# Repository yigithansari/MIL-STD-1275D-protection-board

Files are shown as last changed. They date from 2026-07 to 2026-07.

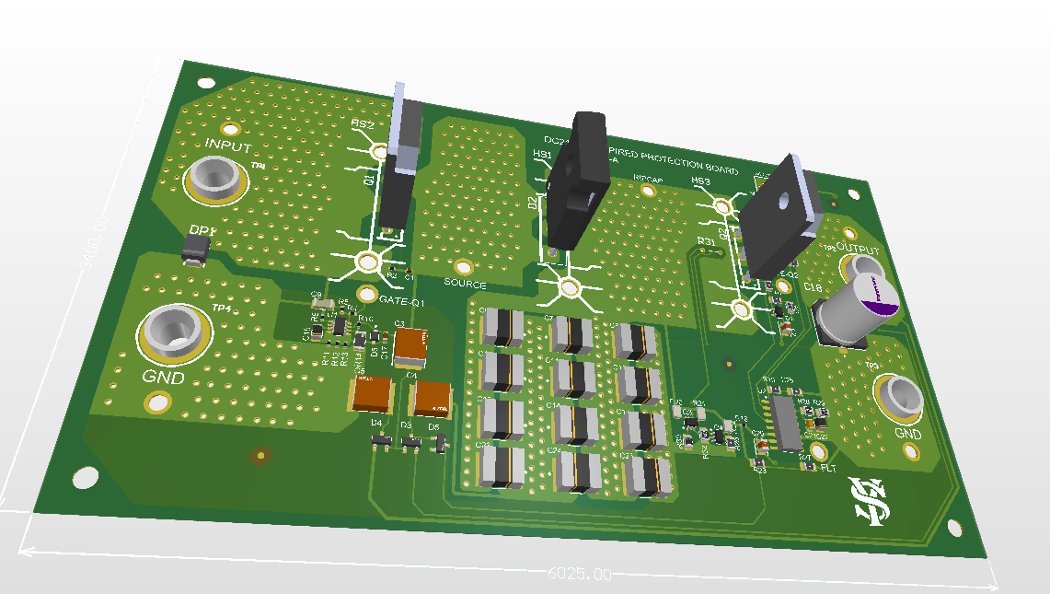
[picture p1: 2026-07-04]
images/pcb-renders/MIL_STD_1275D.png

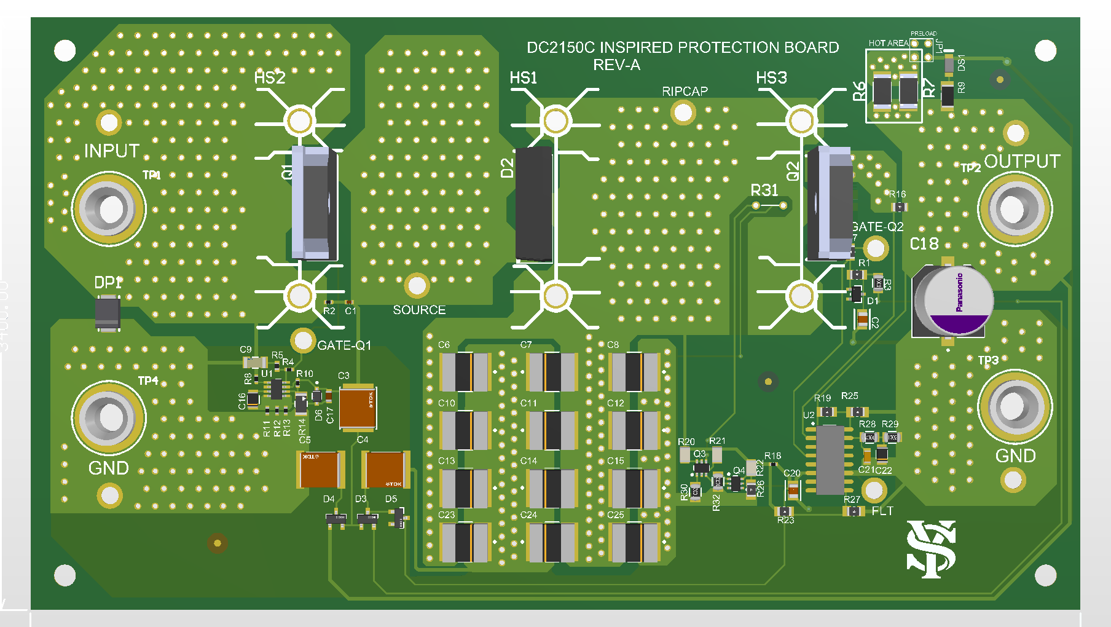
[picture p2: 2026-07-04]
images/pcb-renders/MIL_STD_1275D-TOP.png

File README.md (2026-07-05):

\# MIL-STD-1275D Inspired Protection Board

This repository documents a two-layer PCB design project for a 24 V military vehicle input protection board inspired by the Analog Devices DC2150C reference design.

The goal of this project was to study the DC2150C protection architecture, extract the recommended functional blocks and BOM structure, and recreate the schematic and PCB layout in Altium Designer as a hardware design portfolio project.

The board is focused on harsh DC input environments, especially MIL-STD-1275D-like 24 V / 28 V vehicle power bus conditions. It is not presented as a certified or fully validated MIL-STD-1275D-compliant product.

\## Project Status

Design completed.

This board has not yet been manufactured or electrically tested. The repository is shared as a design-only PCB portfolio project.

\## Design Objective

The objective of this design was to create a protection board for a nominal 24 V military vehicle input line using a DC2150C-inspired architecture.

The design focuses on:

\- Input transient protection

\- Surge stopper architecture

\- High-energy power path layout

\- Anti-ripple capacitor bank

\- Protected output generation

\- Current sensing

\- Reverse input blocking path based on the reference design structure

\- Two-layer manufacturable PCB layout

\## Reference Design Background

This project was inspired by the DC2150C reference design.

The original DC2150C architecture was studied to understand the functional role of each protection block. Based on that study, the schematic and PCB layout were recreated in Altium Designer as an independent design exercise.

This project should be understood as a learning and portfolio-oriented PCB implementation, not as a direct commercial product.

\## Main Functional Blocks

The schematic is divided into the following functional sections:

\- Power Guardian

\- LTC4366 front-end protection stage

\- Anti-ripple capacitor bank

\- Charge pump

\- LT4363 surge stopper stage

\- Input/output connection and indicator section

\## Key Components

Main components used in the design include:

\- `LTC4366`: High-voltage surge stopper controller used in the front-end protection section

\- `LT4363HS-2#PBF`: Surge stopper controller used for the protected output stage

\- External N-channel MOSFETs for the controlled power path

\- Bidirectional TVS diode at the input

\- Power diode path for reverse input blocking based on the DC2150C-inspired architecture

\- Current sense resistor for the LT4363 current limit path

\- Anti-ripple capacitor bank

\- Output capacitor for protected output stabilization

\- Status LED and output connection components

\## Protection Strategy

The protection architecture is based on a staged approach.

The input first passes through a front-end protection stage based around the LTC4366. This section controls the first MOSFET power path and helps protect the downstream circuit from high-voltage input transients.

The anti-ripple section uses a capacitor bank to support the intermediate supply node during ripple and transient conditions.

The LT4363-based surge stopper section controls the protected output path, monitors current through a sense element, and provides additional protection behavior at the output side.

A bidirectional TVS diode is included at the input as an additional transient suppression element. A power diode path is used as part of the reverse input protection approach inspired by the DC2150C reference design.

\## PCB Design

The board was designed as a two-layer PCB.

A two-layer stack-up was selected because the design is primarily a power-path protection board rather than a dense mixed-signal circuit. The layout uses wide copper areas for high-current paths and thermal spreading, while keeping the design simple to inspect and manufacture.

Main layout considerations:

\- Wide copper pours for input, source, RIPCAP, and output nodes

\- Large power pads for input and output terminals

\- Thermal via arrays under high-current and heat-generating copper areas

\- Separate placement of control ICs from main power copper regions

\- Short routing around MOSFET gate-drive and sense paths

\- Clearly labeled test points and power nodes

\- Board-level silkscreen labels for major functional nodes

\## Repository Structure

```text

mil-std-1275-protection-board/

├── README.md

├── hardware/

│   ├── altium-project/

│   ├── schematic-pdf/

│   ├── pcb-pdf/

│   ├── fabrication-outputs/

│   │   ├── gerber/

│   │   ├── nc-drill/

│   │   └── pick-and-place/

│   ├── bom/

│   

├── docs/

│   ├── design-notes.md

│   ├── protection-strategy.md

│   ├── layout-notes.md

│   └── reference-design-study.md

└── images/

\\\&#x20;   ├── pcb-renders/

\\\&#x20;   ├── schematic/

\\\&#x20;   └── layout/

\\\\## Hardware Files

The hardware package includes:

\\\\- Altium Designer project files

\\\\- Schematic PDF

\\\\- PCB layout PDF

\\\\- Bill of Materials

\\\\- Gerber files

\\\\- NC Drill files

\\\\- Pick and Place files

\\\\- PCB render images

\\\\## Important Note

This project is \\\\\\\*\\\\\\\*MIL-STD-1275D-inspired\\\\\\\*\\\\\\\*, not \\\\\\\*\\\\\\\*MIL-STD-1275D-certified\\\\\\\*\\\\\\\*.

No formal MIL-STD-1275D laboratory compliance testing has been performed. The design is shared as a portfolio project demonstrating schematic reconstruction, component-level understanding, PCB layout practice, and manufacturing output generation for a harsh-environment DC input protection board.

\\\\## Tools Used

\\\\- Altium Designer

\\\\- SmartPDF export

\\\\- PCB manufacturing output generation

\\\\- BOM generation

\\\\## Author

Designed by \\\\\\\*\\\\\\\*Yiğithan Sarı\\\\\\\*\\\\\\\*  

Electrical and Electronics Engineering

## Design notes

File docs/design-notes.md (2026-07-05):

\# Design Notes

This document summarizes the main design decisions behind the MIL-STD-1275D-inspired protection board.

The project was developed as a design-only PCB portfolio project based on studying the DC2150C reference design and recreating its functional architecture in Altium Designer.

\## Design Goal

The goal of this board is to provide a protected DC power path for a nominal 24 V military vehicle input line.

The design focuses on:

\- High-voltage transient protection

\- Surge stopper architecture

\- Ripple hold-up support

\- Current sensing

\- Protected output generation

\- Practical two-layer PCB implementation

\- Manufacturing output preparation

This board is not claimed to be MIL-STD-1275D-certified. It is a MIL-STD-1275D-inspired design exercise and portfolio project.

\## Input Environment

The target input environment is a nominal 24 V / 28 V military vehicle power bus.

Such systems may experience:

\- Load dump-like voltage transients

\- Input voltage surges

\- Ripple on the vehicle supply line

\- Reverse input connection conditions

\- High-current switching stress

\- Harsh electrical transients

The design uses a staged protection approach rather than relying on a single protection component.

\## Functional Architecture

The schematic is divided into several functional blocks:

\- Power Guardian

\- LTC4366 front-end protection

\- Anti-Ripple capacitor bank

\- Charge Pump

\- LT4363 Surge Stopper

\- Connection and indicator section

This block-based structure keeps the schematic easier to read and also reflects the functional flow of the power path.

\## LTC4366 Front-End Stage

The LTC4366 section is used as the front-end high-voltage protection controller.

It controls the first external MOSFET power path and helps protect downstream circuitry from high-voltage input transients.

This stage is located near the input side of the design and works together with the front-end MOSFET and surrounding gate-control components.

\## Anti-Ripple Section

The anti-ripple section includes a capacitor bank connected around the intermediate `RIPCAP` node.

This section helps support the intermediate power node during ripple and transient conditions. Multiple capacitors are used in parallel to increase total capacitance and improve current handling.

The layout uses large copper areas and via stitching around this section to support current flow and thermal spreading.

\## LT4363 Surge Stopper Stage

The LT4363HS-2#PBF section is used as the second surge stopper stage.

This stage controls the output-side MOSFET path and monitors current through a sense element. It provides additional output-side protection and fault handling behavior.

The protected output is taken after this stage.

\## Charge Pump Section

The charge pump section supports the gate-drive and output protection architecture.

It includes diode and capacitor elements arranged to support the required control voltage behavior for the protected output path.

\## Reverse Input Consideration

A separate ideal-diode style reverse polarity protection circuit was not added as an independent block.

Instead, the design follows the reverse input blocking approach used in the DC2150C-inspired architecture, where the power diode path and protection-controller behavior are part of the overall reverse input protection strategy.

This should not be described as a fully verified reverse polarity protection feature unless the board is manufactured and tested under reverse input conditions.

\## PCB Stack-Up Decision

A two-layer PCB was selected.

The main reason is that this design is primarily a power-path protection board, not a dense digital or mixed-signal board.

A two-layer design allows:

\- Large accessible copper areas

\- Easier visual inspection

\- Simpler manufacturing

\- Good thermal spreading through wide copper pours

\- Lower prototype cost

The design uses wide copper paths and thermal via arrays to improve current carrying and heat spreading.

\## Design Status

The schematic and PCB layout are completed.

Manufacturing outputs were generated, including:

\- Gerber files

\- NC Drill files

\- Pick and Place files

\- Bill of Materials

\- Schematic PDF

\- PCB layout PDF

The board has not yet been manufactured or electrically validated.

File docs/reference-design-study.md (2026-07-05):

\# Reference Design Study

This document explains how the DC2150C reference design was used as the basis for this PCB portfolio project.

\## Purpose

The purpose of this project was not to create a completely new surge protection architecture from scratch.

Instead, the goal was to study an existing high-quality reference design, understand its functional blocks, extract the recommended component structure, and recreate the schematic and PCB layout independently in Altium Designer.

This approach was used as a learning exercise for:

\- Reading reference design documentation

\- Understanding protection circuit architecture

\- Reconstructing a schematic

\- Preparing a manufacturable PCB layout

\- Generating production files

\- Documenting a hardware design project for portfolio use

\## Reference Design

The project was inspired by the Analog Devices DC2150C reference design.

The DC2150C architecture was studied to understand how LTC4366 and LT4363-based protection stages can be combined in a harsh DC input protection board.

This project follows the general functional structure of the reference design, but the schematic and PCB layout were recreated as an independent Altium Designer exercise.

\## Functional Blocks Studied

The following functional blocks were studied and recreated:

\- Input protection section

\- LTC4366 front-end protection stage

\- Power MOSFET control path

\- Anti-ripple capacitor bank

\- Charge pump section

\- LT4363 surge stopper section

\- Current sense network

\- Protected output section

\- Status and connection section

\## Component Selection Approach

The component selection was based on the recommended BOM structure of the reference design.

The goal was to understand why each major component exists in the protection chain rather than only copying component values.

The most important component groups are:

\- Protection controllers

\- External MOSFETs

\- TVS diode

\- Power diode

\- Current sense resistor

\- Timing and feedback resistors

\- Gate resistors

\- Ripple capacitors

\- Output capacitor

\- Indicator components

\- Input and output connectors

\## Schematic Recreation

The schematic was recreated in Altium Designer using a block-based organization.

The major schematic sections are:

\- Power Guardian

\- LTC4366

\- Anti-Ripple

\- Charge Pump

\- Surge Stopper

\- Connection

This structure makes the schematic easier to review and helps show the functional role of each part of the design.

\## PCB Recreation

The PCB was designed as a two-layer board.

The layout was created to reflect the main power flow from input to output.

The main layout priorities were:

\- Wide copper areas for high-current paths

\- Thermal via arrays for heat spreading

\- Clear input/output separation

\- Short gate and sense routing

\- Readable functional labels

\- Manufacturable two-layer structure

\- Clean production output generation

\## Why This Project Matters

Reference designs are an important part of real hardware engineering.

A good engineer should be able to:

\- Read a reference design

\- Understand the purpose of each block

\- Identify critical components

\- Recreate the design in a CAD tool

\- Make layout decisions based on current flow and thermal behavior

\- Generate manufacturing outputs

\- Clearly document design assumptions and limitations

This project was created to demonstrate exactly that workflow.

\## Difference Between Inspired and Certified

This board should be described as:

\- DC2150C-inspired

\- MIL-STD-1275D-inspired

\- Design-only

\- Portfolio-oriented

\- Not manufactured

\- Not electrically tested

It should not be described as:

\- MIL-STD-1275D-certified

\- MIL-STD-1275D-compliant

\- Production-ready

\- Field-validated

\- Tested for military vehicle use

The project demonstrates design understanding and PCB implementation skill, not formal compliance.

\## Future Improvements

Future development could include:

\- Manufacturing the PCB

\- Assembly and visual inspection

\- Low-voltage bring-up

\- Current-limited power testing

\- Gate waveform validation

\- Surge response testing

\- Thermal measurement under load

\- Reverse input test

\- Comparison with the original reference design measurements

\- Design revision after test results

A manufactured and tested revision could later be documented as Rev-B.

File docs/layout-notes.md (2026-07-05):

\# Layout Notes

This document summarizes the PCB layout decisions used in the MIL-STD-1275D-inspired protection board.

The board was designed as a two-layer PCB in Altium Designer.

\## Board Overview

The PCB layout follows the power path from left to right:

\- Input terminal on the left side

\- LTC4366 front-end protection section

\- Intermediate source and RIPCAP areas

\- Anti-ripple capacitor bank in the middle

\- LT4363 surge stopper section on the right side

\- Protected output terminal on the right side

This physical arrangement helps make the current flow easier to understand and inspect.

\## Two-Layer PCB Decision

A two-layer PCB was selected because the circuit is primarily a power-path protection board.

The design does not require high-density digital routing, controlled impedance traces, or complex mixed-signal separation.

A two-layer board provides:

\- Simpler manufacturing

\- Lower prototype cost

\- Easier inspection

\- Large copper areas for current flow

\- Better accessibility for thermal spreading

\- Clear visual separation between power and control areas

\## Copper Area Strategy

Large copper pours are used for the main power nodes.

The main high-current copper regions include:

\- Input

\- Source

\- RIPCAP

\- Output

\- Ground

These wide copper areas reduce resistance, improve current handling, and provide thermal spreading.

\## Thermal Via Arrays

Thermal via arrays are placed inside large copper regions.

These vias help transfer heat between the top and bottom copper layers and improve thermal distribution across the board.

The via arrays are especially useful around:

\- Input copper area

\- Source copper area

\- RIPCAP copper area

\- Output copper area

\- Ground copper regions

\- MOSFET-related copper areas

\## Power Path Placement

The major power components are placed directly along the current path.

This includes:

\- Input protection section

\- External MOSFETs

\- Power diode

\- Anti-ripple capacitor bank

\- Output-side MOSFET

\- Output capacitor

\- Output terminal

This placement reduces unnecessary current-loop length and keeps the board easier to understand.

\## Control IC Placement

The LTC4366 and LT4363 controllers are placed close to their related MOSFETs and sense networks.

This helps keep gate-drive, feedback, timing, and sense paths short.

The control circuitry is kept away from the largest high-current copper areas where possible, while still maintaining short functional connections.

\## Gate Routing

Gate-drive traces are routed carefully because they control the external MOSFETs.

The goal is to keep gate paths:

\- Short

\- Direct

\- Away from noisy high-current switching paths

\- Clearly connected to their local controller sections

The board includes labeled gate-related test points such as `GATE-Q1` and `GATE-Q2`, which can be useful during future bring-up.

\## Sense Routing

The current sense path around the LT4363 section should be treated as a sensitive measurement path.

The routing should avoid unnecessary loop area and should not be mixed with high-current copper in a way that creates measurement error.

This is especially important if the board is manufactured and tested later.

\## Capacitor Bank Layout

The anti-ripple capacitor bank is placed in the central region of the board.

The capacitors are arranged in parallel with wide copper connections and via stitching.

This helps with:

\- Current sharing

\- Ripple handling

\- Thermal distribution

\- Mechanical symmetry

\## Input and Output Terminals

Large input and output pads are used for the main power connections.

The board includes clearly labeled:

\- `INPUT`

\- `OUTPUT`

\- `GND`

\- `SOURCE`

\- `RIPCAP`

These labels improve readability during inspection and future testing.

\## Silkscreen and Labels

The silkscreen includes functional node names and block-related labels.

Important labels include:

\- `INPUT`

\- `OUTPUT`

\- `GND`

\- `SOURCE`

\- `RIPCAP`

\- `GATE-Q1`

\- `GATE-Q2`

\- `HOT AREA`

\- `REV-A`

This makes the board more understandable as a portfolio piece and also helps future debugging.

\## Test Points

Test points are provided for important nodes.

These are useful for future validation because the board has not yet been manufactured or tested.

Potential measurements include:

\- Input voltage

\- Output voltage

\- Source node voltage

\- RIPCAP voltage

\- Gate voltage of Q1

\- Gate voltage of Q2

\- Fault output

\- Ground reference

\## Layout Status

The layout is completed as a design-only revision.

The board has not yet been manufactured, assembled, or electrically tested. Therefore, thermal behavior, surge response, current limit behavior, and actual transient performance remain future validation items.

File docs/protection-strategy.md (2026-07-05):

\# Protection Strategy

This document explains the protection approach used in the MIL-STD-1275D-inspired protection board.

The design is based on a staged power-path protection architecture inspired by the DC2150C reference design.

\## Protection Philosophy

The board is intended for a nominal 24 V military vehicle input line.

Instead of using a single protection element, the design uses multiple functional stages:

1\. Input transient suppression

2\. Front-end surge control

3\. Ripple hold-up support

4\. Output-side surge stopper control

5\. Current sensing

6\. Protected output filtering and stabilization

This staged approach allows each block to handle a different part of the harsh input environment.

\## Input Transient Suppression

A bidirectional TVS diode is included at the input side of the design.

The purpose of the TVS diode is to clamp high-energy transient events and prevent excessive voltage stress from reaching the downstream protection stages.

Because the TVS is bidirectional, it can respond to both positive and negative transient events. However, the actual transient performance must be verified through testing before making any compliance claim.

\## LTC4366 Front-End Protection

The LTC4366 is used as the front-end surge stopper controller.

Its role is to control the first external N-channel MOSFET in the input power path. During high-voltage input events, this stage is intended to regulate or limit the stress passed to the downstream circuitry.

This stage is placed near the input section and works together with:

\- External MOSFET

\- Gate-control resistor network

\- Timing capacitor

\- Feedback network

\- Input transient suppression components

The LTC4366 stage is important because it handles the first major protection function after the input node.

\## Anti-Ripple Capacitor Bank

The `RIPCAP` node is supported by a large capacitor bank.

The capacitor bank helps reduce ripple and provides energy storage for the intermediate protected node.

Multiple capacitors are used in parallel instead of a single large capacitor. This has several advantages:

\- Lower equivalent series resistance

\- Better current sharing

\- Improved ripple handling

\- Better thermal distribution

\- Flexible PCB placement

The capacitor bank is placed in the high-current region of the board and connected with wide copper areas.

\## LT4363 Surge Stopper Stage

The LT4363HS-2#PBF is used in the output-side surge stopper section.

This stage controls the second external MOSFET power path and provides current monitoring through a sense resistor.

The LT4363 section contributes to:

\- Output-side surge protection

\- Current limit behavior

\- Fault detection

\- Controlled output power path behavior

The protected output is generated after this stage.

\## Current Sense Path

A current sense resistor is used in the LT4363 section.

This resistor allows the controller to monitor load current and react to overcurrent conditions according to the controller configuration.

The sense path should be routed carefully because excessive parasitic resistance or noise pickup can affect current-limit behavior.

\## Power Diode Path

A power diode is included as part of the reverse input blocking and ripple-support architecture inspired by DC2150C.

This diode path should be described carefully.

It is better to say:

> The board follows the reverse input blocking approach of the reference architecture using a power diode path and protection-controller behavior.

It should not be described as fully tested reverse polarity protection unless reverse-input testing is actually performed.

\## Output Capacitor

An output capacitor is placed at the protected output.

Its purpose is to support output stability, reduce high-frequency noise, and help smooth the protected output voltage during transient events.

\## Protection Limits

This design has not been manufactured or tested.

Therefore, the following claims should not be made:

\- MIL-STD-1275D compliant

\- MIL-STD-1275D certified

\- Tested against MIL-STD-1275D

\- Validated for military vehicle use

\- Proven reverse polarity protection

The correct description is:

\- MIL-STD-1275D-inspired

\- DC2150C-inspired

\- Design-only PCB portfolio project

\- Not yet manufactured or electrically validated

\## Future Validation

A future validation plan should include:

\- Visual inspection after assembly

\- Continuity and isolation checks

\- Low-voltage power-up test

\- Current-limited input test

\- Output voltage verification

\- Gate waveform measurement

\- Surge controller response verification

\- Reverse input test with current-limited supply

\- Thermal observation under load

\- Controlled transient testing if suitable equipment is available

Only after these tests could the board be described as electrically verified.

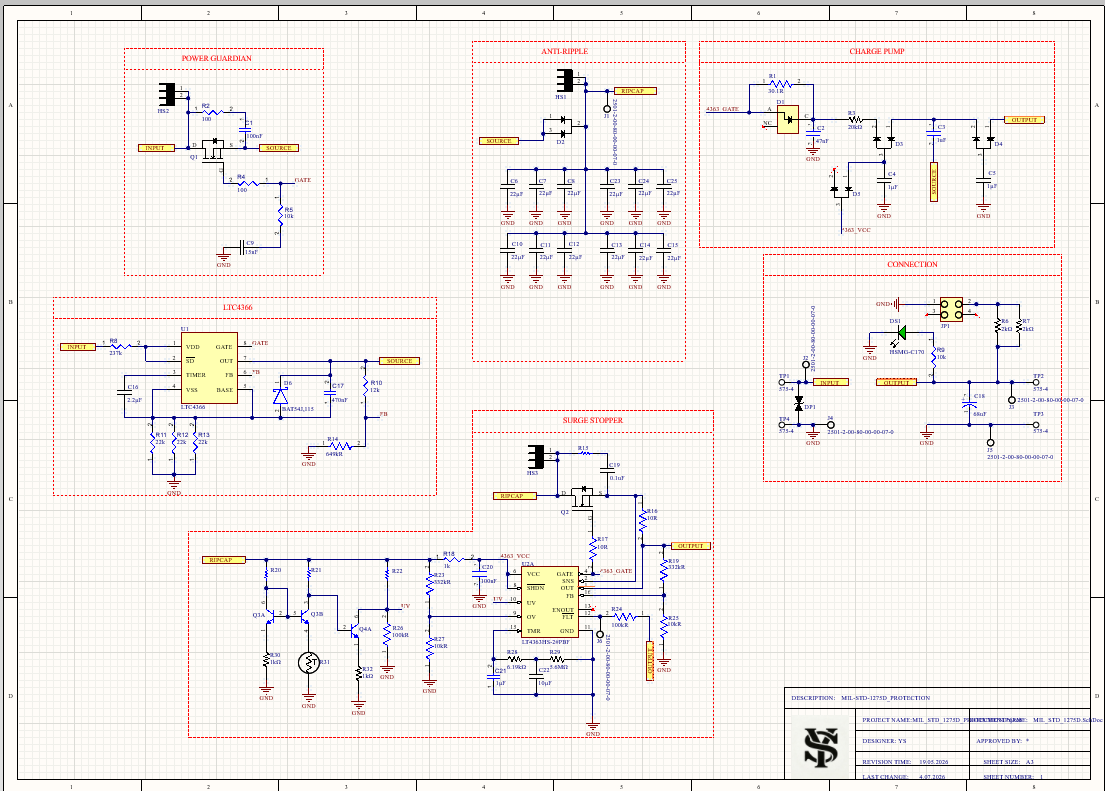
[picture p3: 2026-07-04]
images/schematic.png

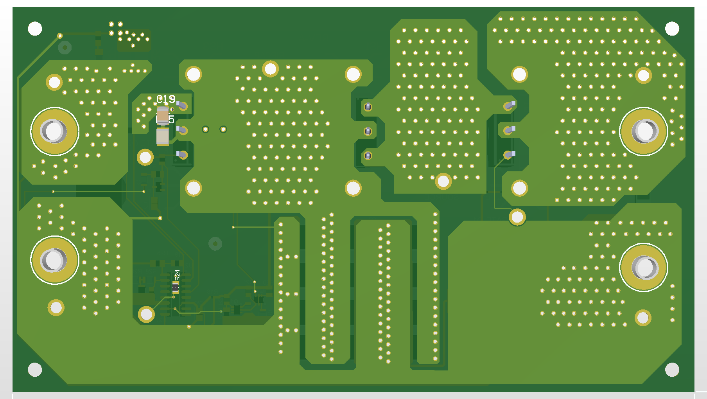
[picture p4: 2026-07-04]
images/pcb-renders/MIL_STD_1275D-BOTTOM.png

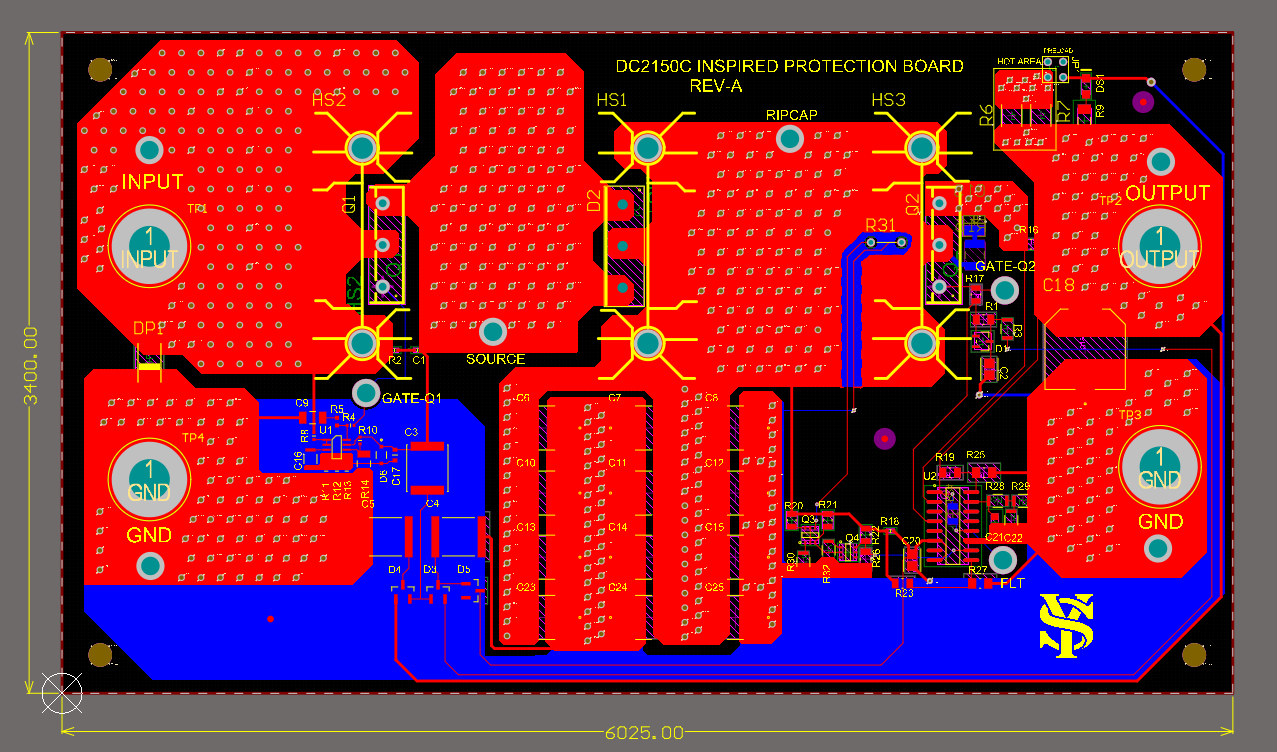
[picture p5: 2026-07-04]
images/pcb-layout/all-layers.png

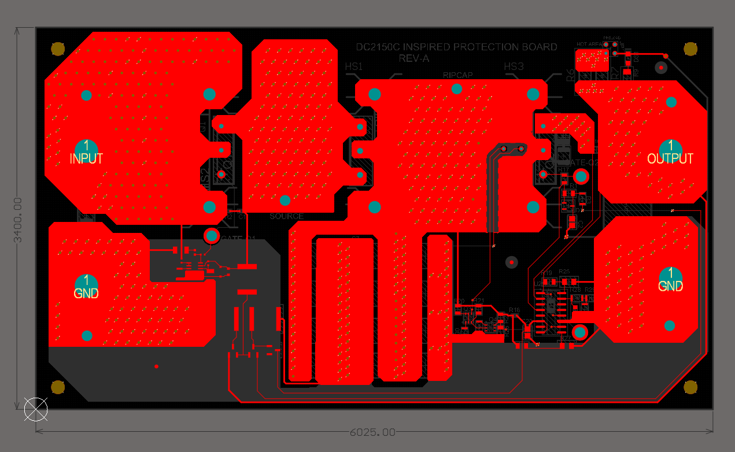
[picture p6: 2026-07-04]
images/pcb-layout/top-layer.png

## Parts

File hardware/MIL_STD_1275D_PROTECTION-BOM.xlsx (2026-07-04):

Name | Description | Designator | Footprint | Quantity | Manufacturer Part Number
Capacitor 100nF +/-20% 25V 0402 | Chip Capacitor, 100nF +/-20%, 25V, 0402, Thickness 0.6 mm | C1 | CAPC0402(1005)60_L | 1
C2012X7R2A473K125AA | Multilayer Ceramic Capacitors 47nF ±10% 100V X7R SMD 0805 | C2 | FP-C2012-125-0_2-IPC_B | 1
C5750X7R2E105K230KA | Multilayer Ceramic Capacitors 1uF ±10% 250V X7R SMD 2220 | C3 | FP-C5750-230-0_4-MFG | 1
CAP_CER_2220_1uF | 250V 1uF X7R 卤10% 2220 Multilayer Ceramic Capacitors MLCC - SMD/SMT ROHS | C4, C5 | CAP_2220 | 2 | C5750X7R2E105K230KA
CAP_CER__SMD_22uF | Multilayer Ceramic Capacitor, CKG Series, 22 - F, - 20%, X7S, 100 V, 2220 [5750 Metric] | C6, C7, C8, C10, C11, C12, C13, C14, C15, C23, C24, C25 | 2 J-LEAD CAP | 12 | CKG57NX7S2A226M500JH
CAP_CER_1206_15nF | Cap Ceramic 0.015uF 100V X7R 10% Pad SMD 1206 125C T/R | C9 | CAP_1206 | 1 | C1206C153K1RACTU
CAP_CER_0805_2.2uF | 25V 2.2uF X7R ±10% 0805 Multilayer Ceramic Capacitors MLCC - SMD/SMT ROHS | C16 | CAP_0805 | 1 | CGA4J3X7R1E225K125AB
Capacitor 470nF +/-20% 25V 0603 | Chip Capacitor, 470nF +/-20%, 25V, 0603, Thickness 1 mm | C17 | CAPC0603(1608)100_L | 1
50SVPF68M | Conductive Polymer Aluminum Solid Capacitors (OS-CON) 68uF ±20% 50V RADIAL SMT 10x12.6mm | C18 | FP-OS-CON-SMT-F12-MFG | 1
CAP_CER_1210_0.1uF | SMD Comm X7R 1210 (3225Metric) ceramic capacitor 0.126Lx0.098W 3.20mmx2.50mm X7R ±10% 0.1muF | C19 | CAP_1210 | 1
C2012X7R2A104K125AA | Multilayer Ceramic Capacitors 100nF ±10% 100V X7R SMD 0805 | C20 | FP-C2012-125-0_2-IPC_B | 1
Capacitor 1uF +/- 10% 16V 0603 | Chip Capacitor, 1 uF, +/- 10%, 16 V, 0603 (1608 Metric) | C21 | CAPC1608X90X35ML15T15 | 1
CAP_CER_0805_10uF | 16V 10uF X7R 卤10% 0805 Multilayer Ceramic Capacitors MLCC - SMD/SMT ROHS | C22 | CAP_0805 | 1 | CL21B106KOQNNNE
DIODE_SMD_250V | Rectifier Diode, 1 Phase, 1 Element, 0.2A, 250V V(RRM), Silicon | D1 | SOT_323 | 1 | BAS21W-7-F
Rectifier Diode, 1 Phase, 2 Element | Rectifier Diode, 1 Phase, 2 Element, 15A, 400V V(RRM), Silicon, TO-247AD | D2 | TO-247AD | 1 | FEP30GP-E3/45
Rectifier Diode Small Signal Switching | Rectifier Diode Small Signal Switching 350V 0.225A 50ns 3-Pin SOT-23 T/R | D3, D4, D5 | SOT-23 | 3 | MMBD3004S-7-F
BAT54J,115 | DIODE SCHOTTKY 30V 200MA SOD323F | D6 | FP-SOD323F-MFG | 1
TVS | Trans Voltage Suppressor Diode, 600W, 128V V(RWM), Bidirectional, 1 Element, Silicon, DO-214AA | DP1 | DO-214AA | 1 | P6SMB150CA-E3/52
HSMG-C170 | Chip LED, Green, 2.2 V, -40 to 85 degC, 2-Pin SMD, Pb-Free, Tape and Reel | DS1 | AVAG-HSMX-C170_V | 1
HEAT_SINK | Heat Sink SOT-32, TO-220, TOP-3 Aluminum Board Level, Vertical | HS1, HS2, HS3 | HS_VERTICAL | 3 | V8813X
CONNECTOR | Board Connector, 4 Contact(s), 2 Row(s), Male, Straight, 0.079 inch Pitch, Solder Terminal | JP1 | CONNECTOR_NRPN022PAEN-RC | 1 | NRPN022PAEN-RC
N-CH MOSFET | PolarHT Series 300 V 88 A 40 mOhm Single N-Channel MOSFET - TO-3P, Trans MOSFET N-CH 100V 170A 3-Pin(3+Tab) TO-3P | Q1, Q2 | TO-3P | 2 | IXTQ88N30P, IXTQ170N10P
MMDT5551-7-F | Dual NPN Small Signal Surface Mount Transistor, 160 V, 200 mA, -55 to 150 degC, 6-Pin SOT-363, RoHS, Tape and Reel | Q3, Q4 | DIOD-SOT-363-6_L | 2
CRCW080530R1FKEA | RES Thick Film, 30.1Ω, 1%, 0.125W, 100ppm/°C, 0805 | R1 | FP-CRCW0805-e3-IPC_B | 1
Resistor 100R +/-1 % 0402 63 mW | Chip Resistor, 100 Ohms, +/-1 %, 63 mW, -55 to 155 degC, 0402 | R2, R4 | RESC0402(1005)_L | 2
RES_0805_20K | Fixed Resistor, Metal Glaze/Thick Film, 0.125W, 20000ohm, 150V, 5% +/-Tol, Surface Mount, 0805 | R3 | RES_0805 | 1 | CRCW080520K0JNEA
Resistor 10k +/-1% 0402 63 mW | Chip Resistor, 10 KOhm, +/- 1%, 63 mW, -55 to 155 degC, 0402 (1005 Metric) | R5 | RESC1005X40X25ML05T05 | 1
RES_SMD_2K_2010 | Res Thick Film 2010 2K Ohm 1% 1W ±100ppm/C Pad SMD T/R Automotive AEC-Q200 | R6, R7 | RES_2010 | 2 | CRCW20102K00FKEFHP
Resistor 237K +/-1 % 0402 63 mW | Chip Resistor, 237 kOhms, +/-1 %, 63 mW, -55 to 155 degC, 0402 | R8 | RESC0402(1005)_L | 1
Resistor 10k +/-1% 1206 250 mW | Chip Resistor, 10 KOhm, +/- 1%, 0.25 W, -55 to 155 degC, 1206 (3216 Metric) | R9 | RESC3216X60X45ML15T20 | 1
12KR2F | 12K 0.063W 1% 0402 (1005 Metric) SMD | R10 | RESC0402(1005)_L | 1
22KR2F | 22K 0.063W 1% 0402 (1005 Metric) SMD | R11, R12, R13 | RESC0402(1005)_L | 3
CRCW1206649KFKEA | RES Thick Film, 649kΩ, 1%, 0.25W, 100ppm/°C, 1206 | R14 | FP-CRCW1206-e3-MFG | 1
CRCW1210100RJNEAHP |  | R15 | RESC3225X60X45NL20T20 | 1
CRCW080510R0JNEA | RES Thick Film, 10Ω, 5%, 0.125W, 200ppm/°C, 0805 | R16, R17 | FP-CRCW0805-e3-IPC_C | 2
1KR2J | 1K 0.063W 5% 0402 (1005 Metric) SMD | R18 | RESC0402(1005)_L | 1
CRCW0805332KFKEA | RES Thick Film, 332kΩ, 1%, 0.125W, 100ppm/°C, 0805 | R19, R23 | FP-CRCW0805-e3-IPC_B | 2
CRCW0805301KFKEA |  | R20, R21, R22 | RESC2013X50X30LL20T20 | 3
CRCW0805100KFKEA | RES Thick Film, 100kΩ, 1%, 0.125W, 100ppm/°C, 0805 | R24, R26 | FP-CRCW0805-e3-MFG | 2
CRCW080510K0FKEA | RES Thick Film, 10kΩ, 1%, 0.125W, 100ppm/°C, 0805 | R25, R27 | FP-CRCW0805-e3-IPC_A | 2
RES_0805_6.19K | Fixed Resistor, Metal Glaze/Thick Film, 0.125W, 6190ohm, 150V, 1% +/-Tol, Surface Mount, 0805 | R28 | RES_0805 | 1 | CRCW08056K19FKEA
RES_0805_5.6M | Res Thick Film 0805 5.6M Ohm 5% 0.125W(1/8W) -400ppm/C to 150ppm/C Molded SMD Punched T/R | R29 | RES_0805 | 1 | ERJ-6GEYJ565V
RES_0805_1K | 125mW Thick Film Resistors 150V ±1% ±100ppm/℃ 1kΩ 0805 Chip Resistor - Surface Mount ROHS | R30 | RES_0805 | 1 | CRCW08051K00FKEA
THERMISTOR | Thermistor PTC 100 Ohm 2-Pin Screw Mount Radial Cardboard Strip | R31 | THERMISTOR | 1
RES_SMD_1K_0805 | Resistor Thick Film 0805 1K Ohm 5% 0.125W (1/8W) ±200ppm/C Molded Surface Mount Paper | R32 | RES_0805 | 1 | NRC10J102TRF
575-4 | Banana Jack, Non-Insulated, 1-Pin THD, RoHS, Bulk | TP1, TP2, TP3, TP4 | KSTN-575-4 | 4
LTC4366 | Ms-Hot Swap/High Voltage High Voltage Surge Stopper With Auto-Retry | U1 | TSOT_23 | 1 | LTC4366HTS8-2#TRPBF
LT4363HS-2#PBF | High Voltage Surge Stopper with Current Limit, 4 to 80 V Vin, 16-pin SOP (S-16), -40 to 125 degC, Pb-Free | U2 | LT-S-16_N | 1

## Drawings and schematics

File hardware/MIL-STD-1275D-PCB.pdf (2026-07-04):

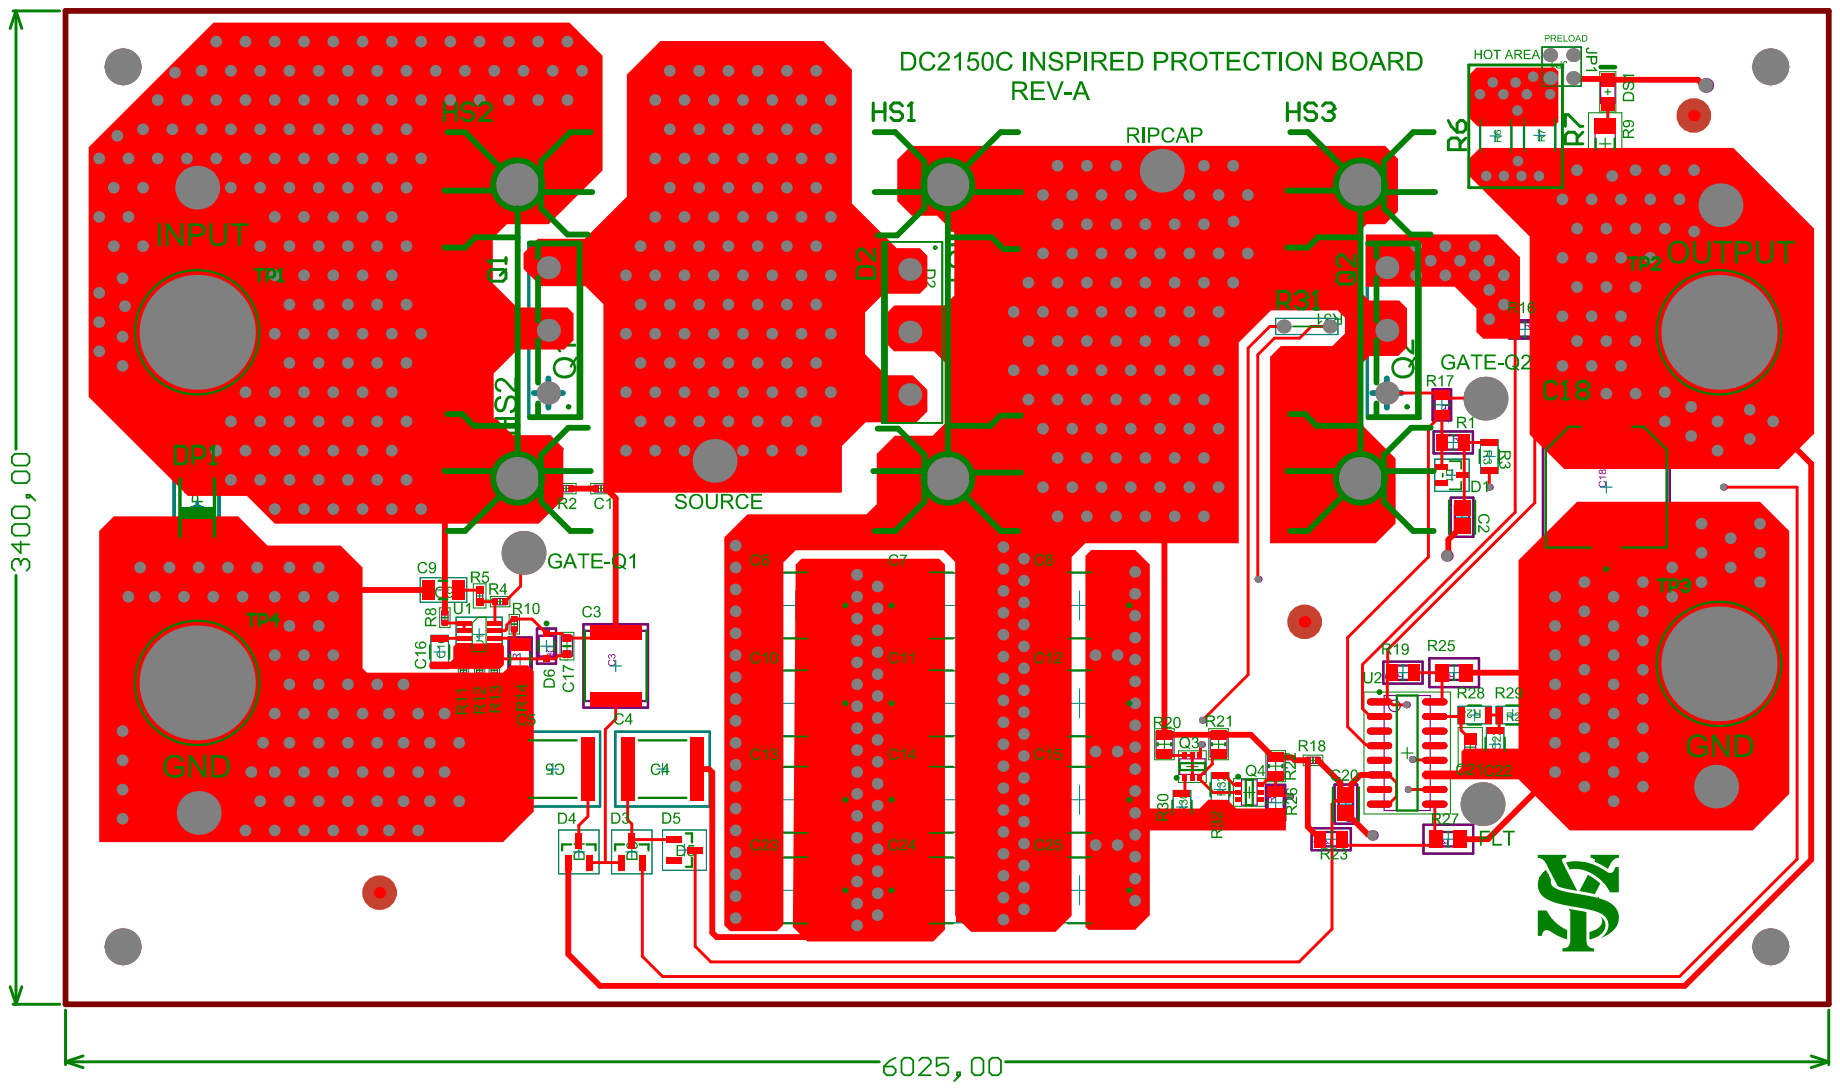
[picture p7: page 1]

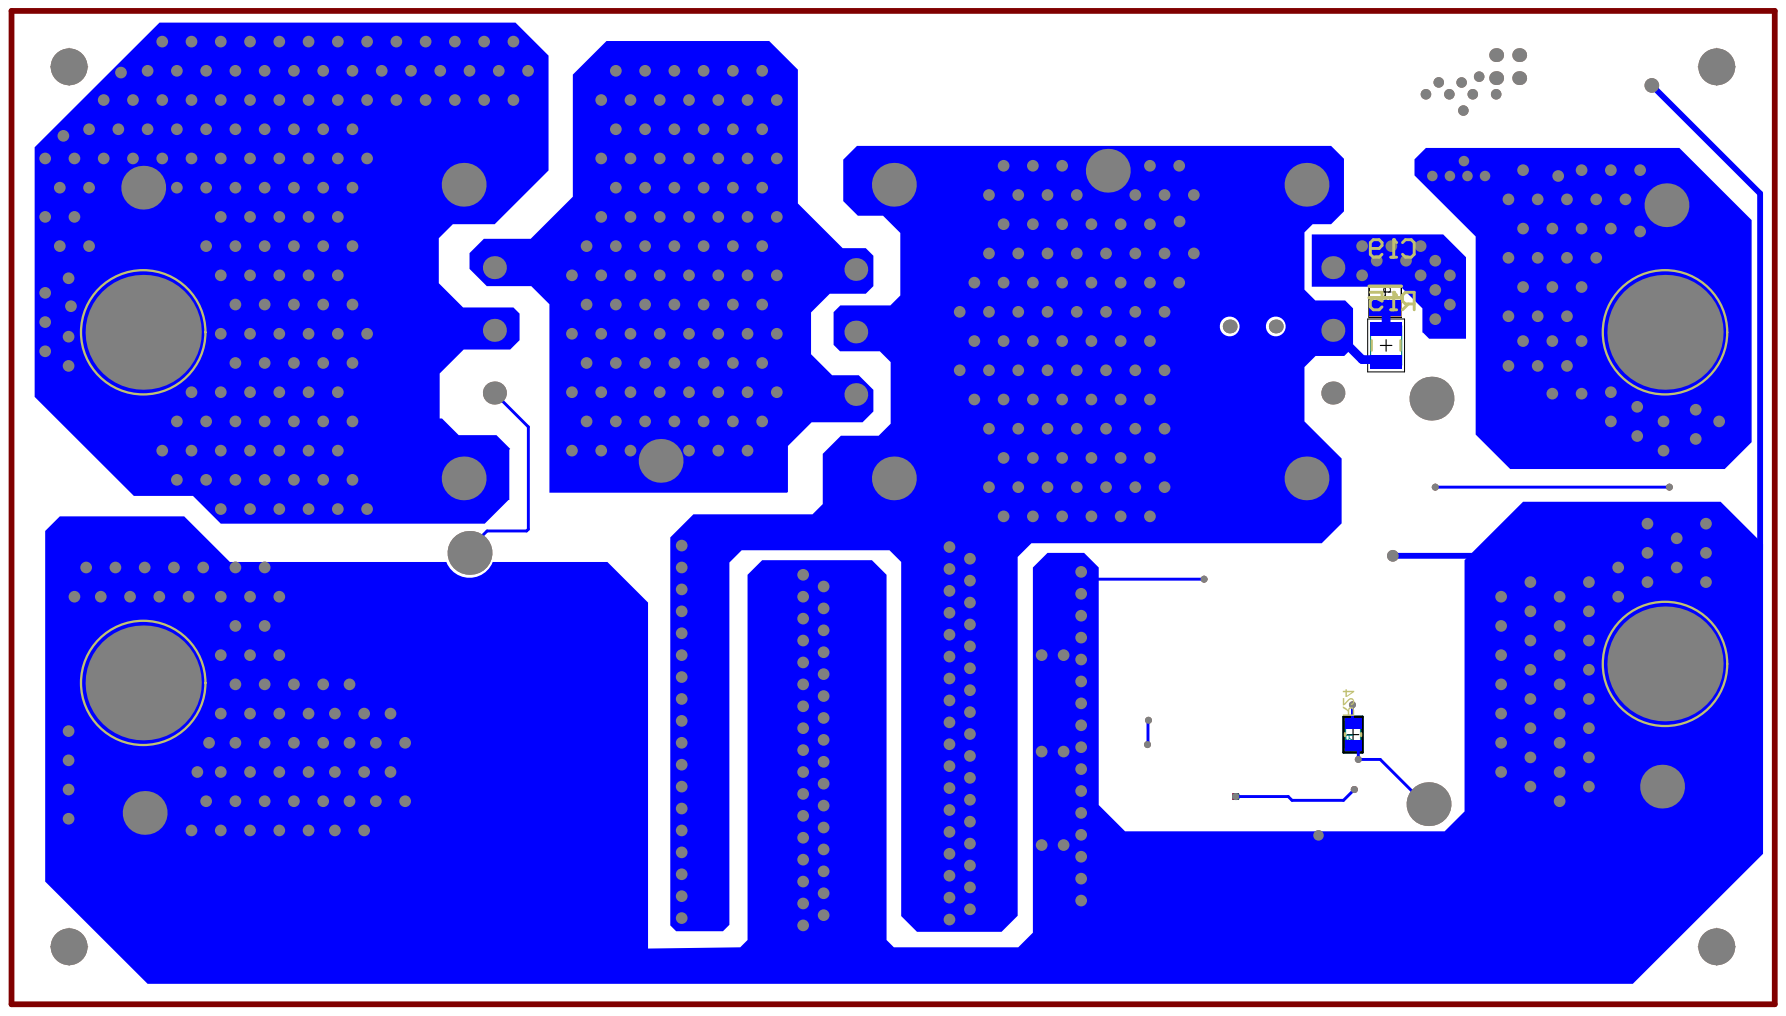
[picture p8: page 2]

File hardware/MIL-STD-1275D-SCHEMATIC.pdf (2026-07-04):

# C3 SOURCE

J6 2501-2-00-80-00-00-07-0 J1 2501-2-00-80-00-00-07-0

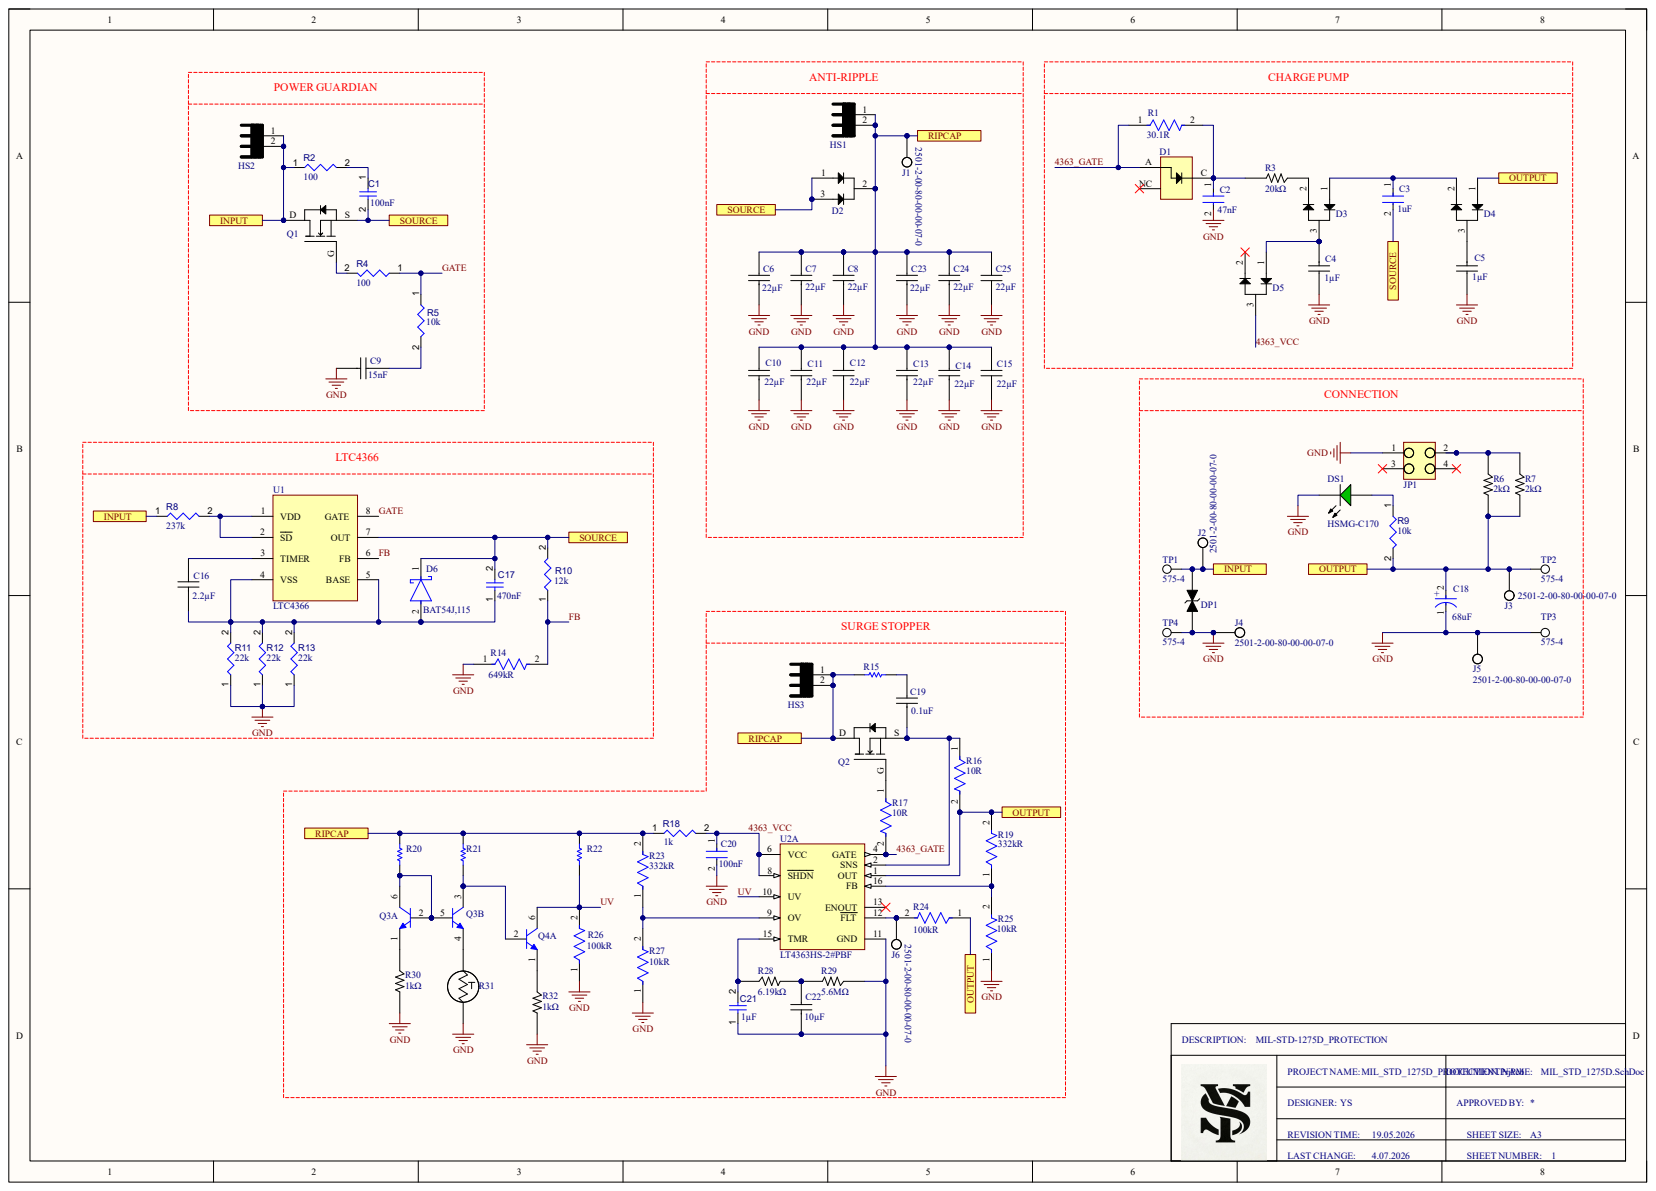
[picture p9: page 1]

PROJECT NAME:MIL_STD_1275D_PROTECTION.PrjPcb DOCUMENT NAME: MIL_STD_1275D.SchDoc

DESIGNER: YS | APPROVED BY: *

REVISION TIME: 19.05.2026 | SHEET SIZE: A3

LAST CHANGE: 4.07.2026 | SHEET NUMBER: 1
